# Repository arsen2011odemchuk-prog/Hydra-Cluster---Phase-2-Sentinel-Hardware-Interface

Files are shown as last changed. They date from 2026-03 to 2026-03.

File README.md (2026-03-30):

#  Phase 2: Sentinel Hardware Interface
### *Custom 3D-Printed Security Console & Telemetry Bridge*

##  Project Overview
**The Sentinel** is a custom hardware peripheral designed to act as a physical "Gatekeeper" for the Hydra Cluster. This phase focuses on **Human-Machine Interface (HMI)** design and hardware-level security. 

Instead of an independent PC, the Sentinel leverages the processing power of the **Phase 1 Master Node**, functioning as a dedicated hardware security module and telemetry dashboard.

---

##  Hardware Integration & Logic

### 1. Host-Powered Architecture
To maximize efficiency, the Sentinel Console connects directly to the Master Node:
*   **Display:** Powered via HDMI, providing a dedicated 7-inch "Heads-Up Display" (HUD) for cluster metrics.
*   **Data Bridge:** The Raspberry Pi Pico communicates with the host OS over a **Serial-over-USB** interface.

### 2. The "Handshake" Security Protocol
The Pico runs a persistent MicroPython loop. It does not allow the Master Node to initiate Phase 3 GPU tasks until a **Hardware Handshake** is successful.
*   **Logic:** The host script waits for a "VALID_AUTH" string from the Pico.
*   **Security:** This ensures that even if the software is compromised, a physical presence is required to "arm" the system.

### 3. Custom 3D-Printed Enclosure
The entire unit is housed in a bespoke, 3D-printed chassis. 
*   **Material:** PLA (Polylactic Acid).
*   **Design Focus:** Integrated internal cable management to hide the HDMI and USB tethers, presenting a clean, professional "Control Center" aesthetic.
## Diagrams 



---

## 📊 Bill of Materials (BOM)

| Component | Model | Purpose | Price (GBP) |Link|
| :--- | :--- | :--- | :--- |:---|
| **Telemetry UI** | 7" HDMI IPS Touchscreen | System Monitoring & UI | £27.19 |[amazon](https://www.amazon.co.uk/FOLOSAFENAR-Capacitive-Touchscreen-Resolution-Compatible/dp/B0CDH6GTNQ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)|
| **Auth Hardware** | 2x RC522 RFID Modules | Dual-Key Physical Security | £6.24 |[amazon](https://www.amazon.co.uk/Hailege-2pcs-RFID-Reader-Module/dp/B0DRCRLJ8R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)|
|Festerness|16 mm Stainless Steel Screws M3|Componing mounting|£7.59|[amazon](https://www.amazon.co.uk/Stainless-Screws-Tapping-Hardware-Fasteners/dp/B0G1TVGBHY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мм%2Bsharp%2Bend%2Caps%2C306&sr=8-7&th=1)|
|Festerness|Double Sided Tape Heavy Duty|Component mounting|£7.99|[amazon](https://www.amazon.co.uk/KICQOM-Mounting-Removable-Multipurpose-3mx2cmx2mm/dp/B0D9BXLYSC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)
| **Logic Controller** | Raspberry Pi Pico (RP2040) | Hardware-to-OS Firmware | £11.39 |[amazon](https://www.amazon.co.uk/IBest-Pre-Soldered-Pico-Microcontroller-Board/dp/B091TLCNJD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)|
|Enclosure|	1kg PLA Filament(black)|	Custom 3D Printed Chassis	|£12.99|[amazon](https://www.amazon.co.uk/ELEGOO-Filament-Dimensional-Accuracy-Printers/dp/B0F4871GP4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)|
|Cabling|	HDMI|  Cables	Data & Video Interconnect|	£6.92|[amazon](https://www.amazon.co.uk/Certified-Adauxter-HDCP2-2-Compatible-Soundbar/dp/B098T3LSY3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)|
|Cabling| HDMI(adapter)| Cables Data & Video Interconnect|£9.99|[amazon](https://www.amazon.co.uk/RIIEYOCA-Degree-Braided-0-56ft-Supports/dp/B0C4GJFGD6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)|
|Sound|Buzzer, 3-24V Piezo Electronic Tone Buzzer Alarm Continuous Sound Cable|Sound that it worked|4.59|[amazon](https://www.amazon.co.uk/Electronic-Continuous-electronic-component-assortment/dp/B07YG9WQMX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)|
| **TOTAL** | | | **£94.89/$125,09** |

---

## 🛠️ Software & Firmware Stack
*   **MicroPython:** Polling RFID UIDs and controlling status LED indicators.
*   **Docker:** Containerization of monitoring services on the internal Micro-PC.
*   **MQTT/Serial:** Protocol for transmitting security status between the Console and the Cluster.

---
##  Wiring Diagram (Pinout)
| Component | Module Pin | Pico Pin (GPIO) | Physical Pin # | Signal Type |
| :--- | :--- | :--- | :--- | :--- |
| **RFID Reader L (Master)** | SDA (SS/CS) | **GP17** | 22 | SPI0 CS |
| | SCK | **GP18** | 24 | SPI0 SCK |
| | MOSI (TX) | **GP19** | 25 | SPI0 TX |
| | MISO (RX) | **GP16** | 21 | SPI0 RX |
| | RST | **GP20** | 26 | Reset |
| | 3.3V | **3.3V(OUT)** | 36 | Power |
| | GND | **GND** | 38 | Ground |
| **RFID Reader R (Slave)** | SDA (SS/CS) | **GP13** | 17 | SPI1 CS |
| | SCK | **GP10** | 14 | SPI1 SCK |
| | MOSI (TX) | **GP11** | 15 | SPI1 TX |
| | MISO (RX) | **GP8** | 11 | SPI1 RX |
| | RST | **GP9** | 12 | Reset |
| | 3.3V | **3.3V(OUT)** | 36 | Power |
| | GND | **GND** | 13 | Ground |
| **Active Buzzer** | (+) Positive | **GP15** | 20 | Digital Output |
| | (-) Negative | **GND** | 18 | Ground |
| **7" IPS Screen** | HDMI | **N/A** | External | Video Feed |
| | Micro-USB | **N/A** | External | Power / Touch |

---

## 🛠️ Assembly & Wiring Notes

### 1. SPI Bus Separation
The system uses **Dual-SPI architecture**. This prevents data collisions between the two RFID readers, allowing the Pico to poll both authentication slots simultaneously without lag.

### 2. Power Strategy
- **7" IPS Screen:** MUST be powered directly from the Master Node (PC) USB port. Do NOT power the screen via the Pico pins, as the current draw exceeds the Pico's limits.
- **RFID Modules:** Powered by the Pico's 3.3V(OUT) pin. For extra stability, add a 10µF capacitor between VCC and GND if you experience read errors.
- **Pico:** Powered via the Micro-USB cable, which also acts as the Data Bridge for the `Rolling Password` protocol.

### 3. Cable Management (No-Holder Build)
- Use **3M VHB Double-Sided Tape** to secure the RFID modules against the front panel.
- Ensure the **antenna side** (the loop on the PCB) of the RFID reader is facing the plastic wall (2.5mm thickness).
- Keep SPI jumper wires under **20cm** to avoid electromagnetic interference (EMI).

### 4. Buzzer Polarity
The Active Piezo Buzzer is polarity-sensitive:
- **Long Leg (+):** Connect to GP15.
- **Short Leg (-):** Connect to GND.

---

##  System Logic Flow (The "Sentinel" Protocol)

```mermaid
graph TD
    Start[Power On] --> Init[Init SPI0 & SPI1]
    Init --> Idle{Scanning Slots...}
    
    Idle -->|Card 1 Detected| Check2{Card 2 Present?}
    Check2 -->|No / Timeout| Error[Access Denied: Dual-Auth Required]
    Check2 -->|Yes| Validation{Check Whitelist}
    
    Validation -->|Match| Grant[Serial: AUTH_GRANTED]
    Validation -->|Mismatch| Alert[Serial: SECURITY_ALERT]
    
    Grant --> Monitor{Keep-Alive Loop}
    Monitor -->|Card Removed| Revoke[Serial: SESSION_TERMINATED]
    Revoke --> Idle
    Error --> Idle

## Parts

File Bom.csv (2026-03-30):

Component | Model | Purpose | Price_GBP | Source
Telemetry UI | 7" HDMI IPS Touchscreen | System Monitoring & UI | £27.19 | https://www.amazon.co.uk/FOLOSAFENAR-Capacitive-Touchscreen-Resolution-Compatible/dp/B0CDH6GTNQ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
Auth Hardware | 2x RC522 RFID Modules | Dual-Key Physical Security | £6.24 | https://www.amazon.co.uk/Hailege-2pcs-RFID-Reader-Module/dp/B0DRCRLJ8R
Logic Controller | Raspberry Pi Pico (RP2040) | Hardware-to-OS Firmware | £11.39 | https://www.amazon.co.uk/IBest-Pre-Soldered-Pico-Microcontroller-Board/dp/B091TLCNJD?s=computers
Enclosure | 1kg PLA Filament(black) | Custom 3D Printed Chassis | £12.99 | https://www.amazon.co.uk/ELEGOO-Filament-Dimensional-Accuracy-Printers/dp/B0F4871GP4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
Fasteners | 16mm Stainless Steel Screws M3 | Component mounting | £7.59 | https://www.amazon.co.uk/Stainless-Screws-Tapping-Hardware-Fasteners/dp/B0G1TVGBHY?rnid=118657031
Mounting | Double Sided Tape Heavy Duty | Glue-free component fix | £7.99 | https://www.amazon.co.uk/KICQOM-Mounting-Removable-Multipurpose-3mx2cmx2mm/dp/B0D9BXLYSC
Cabling | HDMI Cable (Standard) | Video Interconnect | £6.92 | https://www.amazon.co.uk/Certified-Adauxter-HDCP2-2-Compatible-Soundbar/dp/B098T3LSY3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
Cabling | HDMI 90 Degree Adapter | Space-saving connector | £9.99 | https://www.amazon.co.uk/RIIEYOCA-Degree-Braided-0-56ft-Supports/dp/B0C4GJFGD6
Sound | Active Piezo Buzzer 3.3V | Acoustic Auth Feedback | £4.59 | https://www.amazon.co.uk/Electronic-Continuous-electronic-component-assortment/dp/B07YG9WQMX
TOTAL |  |  | 94.89/$125.09

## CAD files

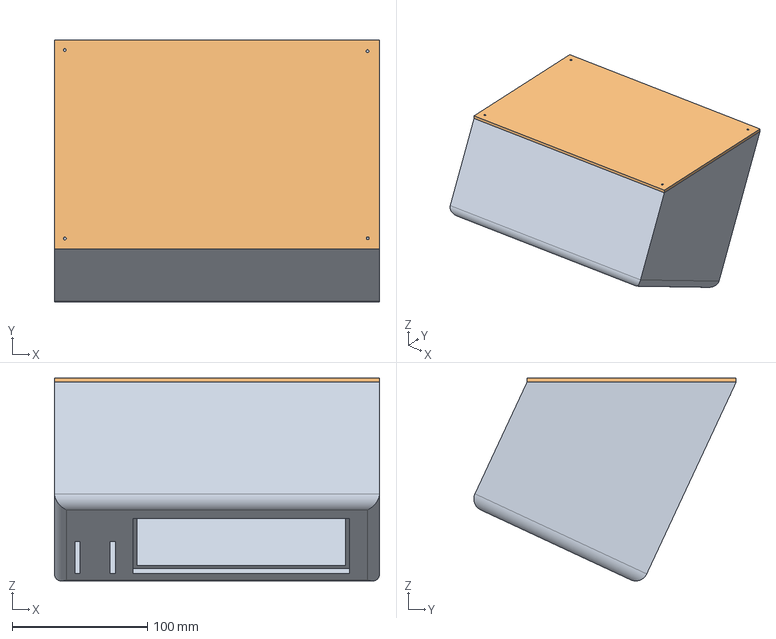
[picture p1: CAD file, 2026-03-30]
Phase 2.step
240.0 x 193.8 x 149.8 mm

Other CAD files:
Untitled.stl

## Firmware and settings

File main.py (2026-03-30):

This firmware implements a Dual-Bus SPI isolation strategy to prevent hardware race conditions between authentication slots. The logic follows the "Dead-Man-Switch" protocol: if either physical key is removed from the Sentinel chassis, the Pico immediately broadcasts a TERMINATE signal via the Serial Bridge to the Master Node, forcing an instant lock of the GPU Cluster. All data is transmitted in JSON format for seamless integration with the Phase 2 Telemetry HUD.



import machine
import utime
import ujson
from mfrc522 import MFRC522

class SentinelInterface:
    def __init__(self):
        # 1. Инициализация Зуммера
        self.buzzer = machine.Pin(15, machine.Pin.OUT)
        
        # 2. Инициализация SPI0 (Левый RFID)
        self.reader_l = MFRC522(spi_id=0, sck=18, miso=16, mosi=19, cs=17, rst=20)
        
        # 3. Инициализация SPI1 (Правый RFID)
        self.reader_r = MFRC522(spi_id=1, sck=10, miso=8, mosi=11, cs=13, rst=9)
        
        # Белый список (UID карт) — замени на свои после первого теста
        self.whitelist = ["0xABC123", "0xXYZ789"] 
        self.is_authorized = False

    def beep(self, duration=0.1):
        """Звуковой сигнал подтверждения."""
        self.buzzer.value(1)
        utime.sleep(duration)
        self.buzzer.value(0)

    def get_uid(self, reader):
        """Чтение UID с конкретного модуля."""
        (stat, tag_type) = reader.request(reader.REQIDL)
        if stat == reader.OK:
            (stat, uid) = reader.SelectTagSN()
            if stat == reader.OK:
                return "0x" + "".join(["%02X" % i for i in uid])
        return None

    def send_status(self, status, key_a=None, key_b=None):
        """Отправка JSON пакета в Serial порт (Master Node)."""
        data = {
            "system": "SENTINEL_PHASE_2",
            "status": status,
            "key_alpha": key_a,
            "key_beta": key_b,
            "timestamp": utime.ticks_ms()
        }
        print(ujson.dumps(data))

    def run(self):
        print("Sentinel Phase 2: System Online")
        self.beep(0.3)
        
        while True:
            uid_l = self.get_uid(self.reader_l)
            uid_r = self.get_uid(self.reader_r)

            # Логика "Two-Man Rule"
            if uid_l and uid_r:
                if not self.is_authorized:
                    self.is_authorized = True
                    self.beep(0.1)
                    utime.sleep(0.1)
                    self.beep(0.1)
                    self.send_status("AUTHORIZED", uid_l, uid_r)
            else:
                if self.is_authorized:
                    self.is_authorized = False
                    self.send_status("TERMINATED")
            
            utime.sleep(0.5) # Частота опроса (Hz)

# Запуск системы
if __name__ == "__main__":
    try:
        sentinel = SentinelInterface()
        sentinel.run()
    except Exception as e:
        print(f"Critical System Failure: {e}")
